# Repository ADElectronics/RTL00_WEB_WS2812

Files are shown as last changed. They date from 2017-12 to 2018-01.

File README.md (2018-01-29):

# Глупая гирлянда на RTL-00 и WS2812

Глупая гирлянда с WEB управлением на основе RTL-00 (RTL8710AF) и WS2812. :)<br>

Описание проекта - [RTL-00, WS2812 — Глупая гирлянда](https://adelectronics.ru/2017/12/29/rtl-00-ws2812-глупая-гирлянда/)<br>
Требуется SDK А для сборки - [RTL_SDK_A](https://github.com/ADElectronics/RTL_SDK_A)<br>

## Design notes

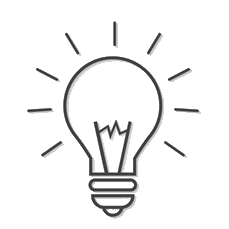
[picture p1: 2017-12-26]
Firmware/WEBFiles/on.gif

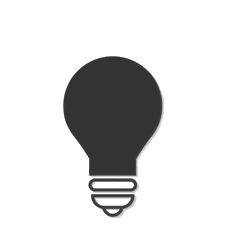
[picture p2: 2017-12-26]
Firmware/WEBFiles/off.gif

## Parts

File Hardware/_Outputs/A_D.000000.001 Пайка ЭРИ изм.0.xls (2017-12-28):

ПЕРЕЧЕНЬ КОМПЛЕКТУЮЩИХ
Глупая гирлянда
A_D.000000.001 Э3
Позиционный номер компонента | Тип компонента | Компонент | Производитель | Спецификация | Количество |  | Примечание
 |  |  |  |  | на ед. | на комплект
A1 | Модуль | RTL-00 | B&T |  | 1 | 1 | RTL-01, PADI-00, MJIOT-AMB-01S
C1, C2, C4, C5, C6 | Конденсатор | GRM188R71C104KA01D | Murata |  | 5 | 5
C3, C7 | Конденсатор | GRM21BR60J226ME39L | Murata |  | 2 | 2
DA1 | Микросхема | MIC5205-3.3YM5 | Micrel |  | 1 | 1 | MIC5205-3.3BM5
DD1 | Микросхема | SN74AVC1T45DBVR | Texas Instruments |  | 1 | 1 | SN74AVC1T45DBVT
HL1 | Индикатор единичный | BL-LS0603GC |  |  | 1 | 1
HL2 | Индикатор единичный | BL-LS0603HC |  |  | 1 | 1
R1, R2, R3, R4 | Резистор | RC0603JR-0710KL | Yageo |  | 4 | 4 | CR0603-JW-103E
R5, R6 | Резистор | RC0603JR-07330RL | Yageo |  | 2 | 2 | CR0603-JW-331E
R7 | Резистор | RC0603JR-074K7L | Yageo |  | 1 | 1
R8 | Резистор | RC0603JR-07100R | Yageo |  | 1 | 1 | CR0603-JW-101E
SB1 | Переключатель | SKQGABE010 | ALPS |  | 1 | 1
VD1 | Диод | SD103CW |  |  | 1 | 1
XP1 | Вилка | PLS-3 |  |  | 1 | 1
XP2 | Вилка | PLS-5 |  |  | 1 | 1
 |  |  |  |  | Комплект плат, ед.:
 |  |  |  |  |  | 1

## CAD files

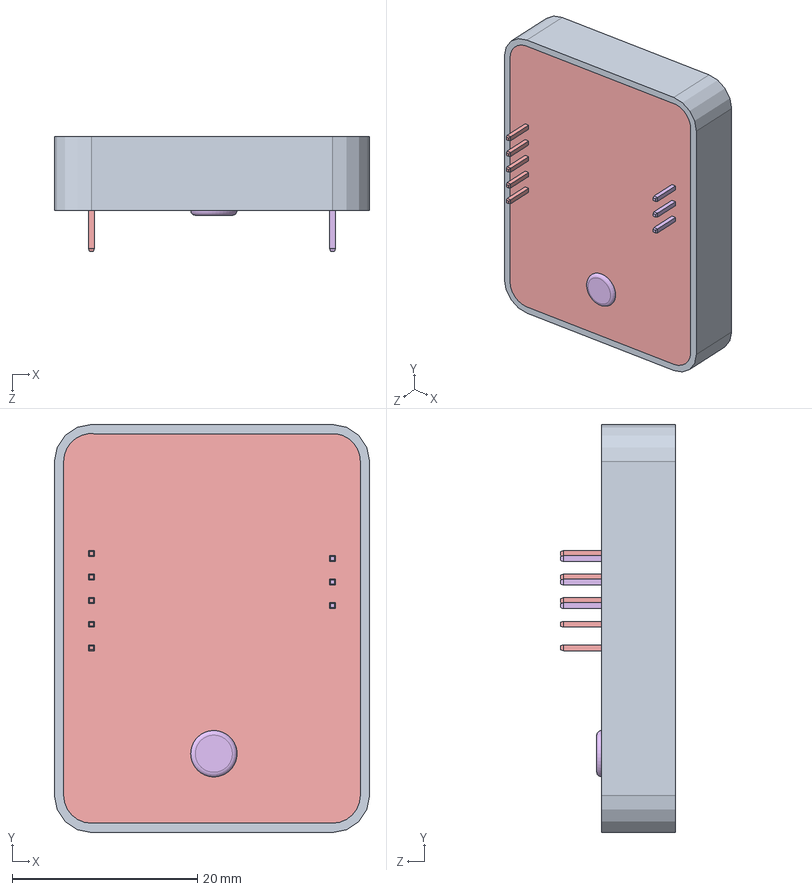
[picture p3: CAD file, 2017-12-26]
Device body/Сборка.SLDASM
34.0 x 44.0 x 12.4 mm
Base
Board
User_Library-Chip_Resistor2 x 5
User_Library-CAPC1608X09 x 5
User_Library-SOD123-1
Extruded
circuitworks-sot-23-5
User_Library-SOT23-6-2
User_Library-CAPC2013X10 x 2
User_Library-button1
Top
Button

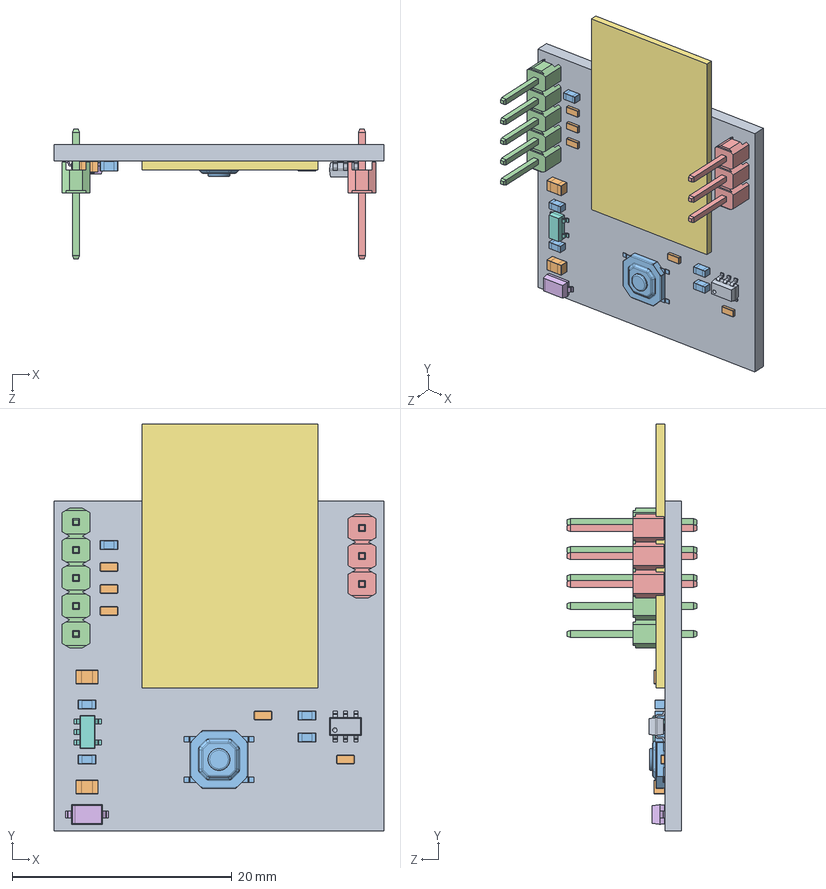
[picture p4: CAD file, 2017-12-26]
Device body/PCB/A_D.000000.001.SLDASM
30.0 x 37.0 x 11.8 mm
Board
User_Library-Chip_Resistor2 x 5
User_Library-CAPC1608X09 x 5
User_Library-SOD123-1
Extruded
circuitworks-sot-23-5
User_Library-SOT23-6-2
User_Library-CAPC2013X10 x 2
User_Library-button1

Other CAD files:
Device body/PCB/A1.sldasm
Device body/PCB/C3.sldasm
Device body/PCB/R1.sldasm
Device body/PCB/C6.sldasm
Device body/PCB/R4.sldasm
Device body/PCB/DD1.sldasm
Device body/PCB/C4.sldasm
Device body/PCB/R2.sldasm
Device body/PCB/C2.sldasm
Device body/PCB/C5.sldasm
Device body/PCB/VD1.sldasm
Device body/PCB/DA1.sldasm
Device body/PCB/C7.sldasm
Device body/PCB/XP1.sldasm
Device body/PCB/SB1.sldasm
Device body/PCB/R5.sldasm
Device body/Base.SLDPRT
Device body/Base.STL
Device body/Button.SLDPRT
Device body/Button.STL
Device body/PCB/324089616.sldasm
Device body/PCB/Board.sldprt
Device body/PCB/C1.sldasm
Device body/PCB/Extruded.sldprt
Device body/PCB/PLS-3.sldprt
Device body/PCB/PLS-5.sldprt
Device body/PCB/R3.sldasm
Device body/PCB/User_Library-CAPC1608X09.sldprt
Device body/PCB/User_Library-CAPC2013X10.sldprt
Device body/PCB/User_Library-Chip_Resistor2.sldprt
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

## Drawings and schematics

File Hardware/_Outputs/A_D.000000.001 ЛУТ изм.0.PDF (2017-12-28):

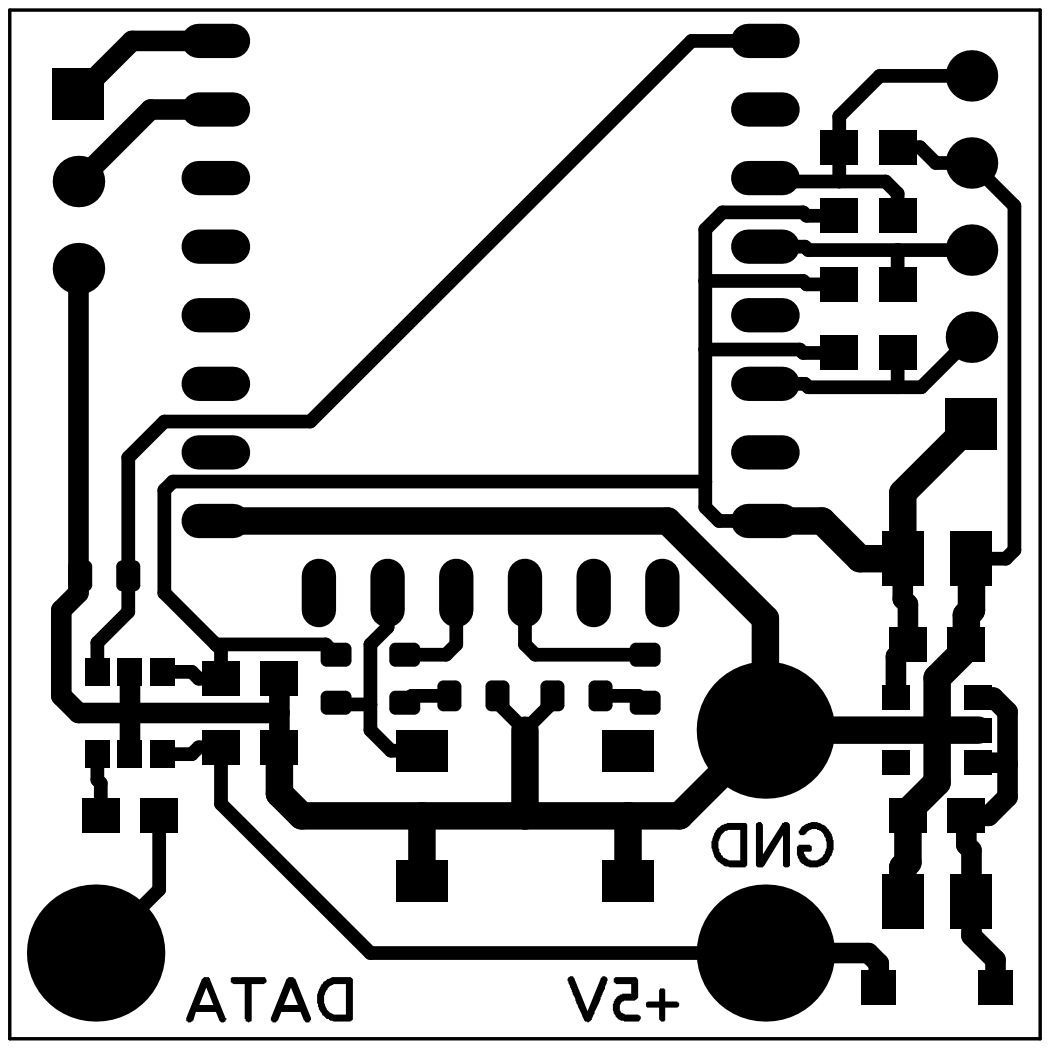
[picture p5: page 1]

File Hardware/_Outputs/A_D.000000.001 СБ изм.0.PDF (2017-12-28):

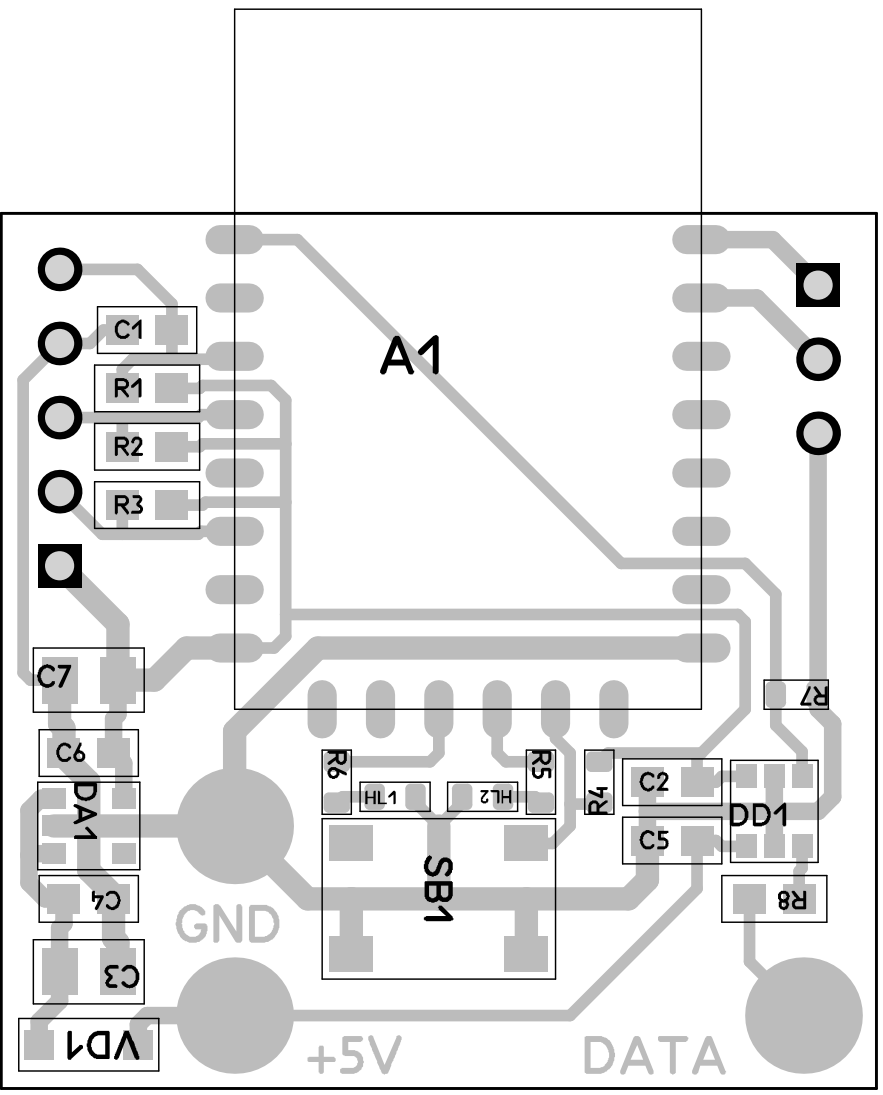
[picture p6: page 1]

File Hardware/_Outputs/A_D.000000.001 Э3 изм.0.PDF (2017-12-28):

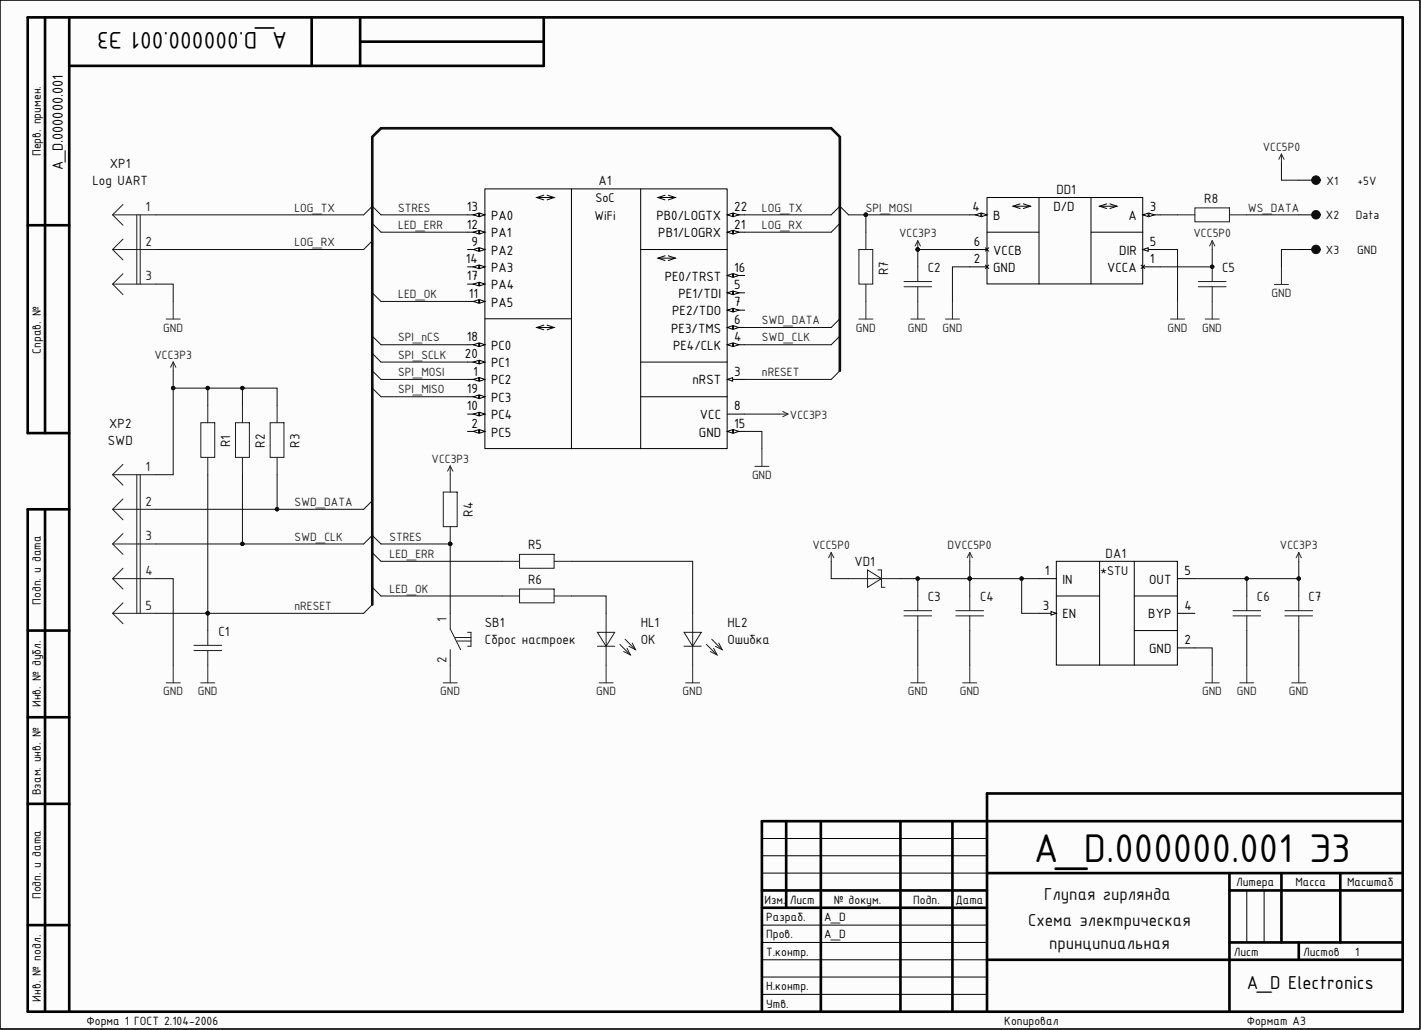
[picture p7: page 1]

PA1 12 PA0 13 | SoC WiFi

PA2 9 | | SWD_DATA

Инв. № подл. Подп. и дата Взам. инв. № Инв. № дубл. Подп. и дата

Глупая гирлянда Схема электрическая принципиальная | Литера | Масса | Масштаб

Изм. | Лист | № докум. | Подп. | Дата
Разраб. | | A_D
Пров. | | A_D
Т.контр. | | | | | Лист | Листов 1

Н.контр.
Утв.

A_D Electronics

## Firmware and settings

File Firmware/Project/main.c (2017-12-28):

#include "platform_autoconf.h"
#include "autoconf.h"
#include "FreeRTOS.h"
#include "task.h"
#include "diag.h"
#include "hal_crypto.h"
#include "hal_log_uart.h"
#include "hal_misc.h"
#include "diag.h"
#include "tcm_heap.h"
#include "hal_platform.h"
#include "rtl8195a_sys_on.h"
#include "hal_timer.h"

#ifdef CONFIG_WDG_ON_IDLE
#include "rtl8195a_wdt.h"
#include "hal_peri_on.h"
#include "rtl8195a_peri_on.h"
#endif

// Customized Signature (Image Name)
#include "section_config.h"
#ifndef _MSC_VER // IntelliSense
SECTION(".custom.validate.rodata")
#endif
const unsigned char cus_sig[32] = "WEB Sample";

#ifdef CONFIG_DEBUG_LOG
#define DEBUG_MAIN_LEVEL CONFIG_DEBUG_LOG
#else
#define DEBUG_MAIN_LEVEL 0
#endif

#ifndef CONFIG_INIT_NET
#define CONFIG_INIT_NET             1
#endif
#ifndef CONFIG_INTERACTIVE_MODE
#define CONFIG_INTERACTIVE_MODE     1
#endif

extern void WDGStart(void);
extern void user_init_thrd(void);
extern void user_ws_thrd(void);

void ShowMemInfo(void)
{
	DiagPrintf("\nCLK CPU\t\t%d Hz\nRAM heap\t%d bytes\nTCM heap\t%d bytes\n", HalGetCpuClk(), xPortGetFreeHeapSize(), tcm_heap_freeSpace());
}

int main(void)
{
#if DEBUG_MAIN_LEVEL > 3
	 ConfigDebugErr  = -1;
	 ConfigDebugInfo = ~(_DBG_SPI_FLASH_);//|_DBG_TCM_HEAP_);
	 ConfigDebugWarn = -1;
	 CfgSysDebugErr = -1;
	 CfgSysDebugInfo = -1;
	 CfgSysDebugWarn = -1;
#endif

#ifdef CONFIG_WDG_ON_IDLE
	HAL_PERI_ON_WRITE32(REG_SOC_FUNC_EN, HAL_PERI_ON_READ32(REG_SOC_FUNC_EN) & 0x1FFFFF);
#if CONFIG_DEBUG_LOG > 3
	WDGInitial(CONFIG_WDG_ON_IDLE * 3000); // 30 s
#else
	WDGInitial(CONFIG_WDG_ON_IDLE * 1000); // 4 s
#endif
	WDGStart();
#endif

#if (defined(CONFIG_CRYPTO_MODULE) && (CONFIG_CRYPTO_STARTUP))
	 if(rtl_cryptoEngine_init() != 0 ) 
	 {
		 DBG_8195A("Crypto engine init failed!\n");
	 }
#endif

#if DEBUG_MAIN_LEVEL > 1
	vPortFree(pvPortMalloc(4)); // Init RAM heap
	ShowMemInfo(); // RAM/TCM/Heaps info
#endif

	// wlan & user_start intialization
	xTaskCreate(user_init_thrd, "user_init", 512, NULL, tskIDLE_PRIORITY + 2 + PRIORITIE_OFFSET, NULL);
	xTaskCreate(user_ws_thrd, "user_ws", 512, NULL, tskIDLE_PRIORITY + 1 + PRIORITIE_OFFSET, NULL);

	// Enable Schedule, Start Kernel
#if defined(CONFIG_KERNEL) && !TASK_SCHEDULER_DISABLED
#ifdef PLATFORM_FREERTOS
	vTaskStartScheduler();
#endif
#else
	RtlConsolTaskRom(NULL);
#endif
}

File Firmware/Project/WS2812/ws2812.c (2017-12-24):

#include "ws2812.h"

/* Quick and dirty, we use one big DMA buffer for the whole strip length.
 * TODO: use smaller DMA buffer and fill in bit patterns on the fly */
uint8_t dma_buffer[WS2812_DMABUF_LEN(WS2812_LEDS_MAX)];

/* scale uint8 value from range 2-255 to range 0-scale */
static inline uint8_t WS2812_Scale(uint8_t value, uint8_t scale)
{
	uint32_t tmp;

	tmp = value * scale;
	tmp /= 256;

	return (uint8_t)tmp;
}

// wake up waiting tasks when DMA transfer is complete 
static void master_tr_done_callback(void *pdata, SpiIrq event)
{
	BaseType_t task_woken, result;
	ws2812_t *cfg;

	task_woken = pdFALSE;
	cfg = (ws2812_t *) pdata;

	switch (event) 
	{
		case SpiRxIrq:
			break;
			
		case SpiTxIrq:
			result = xEventGroupSetBitsFromISR(cfg->events, BIT_DONE, &task_woken);
			if(result == pdPASS)
			{
				portYIELD_FROM_ISR(task_woken);
			}
			break;
			
		default:
			DBG_8195A("WS2812: Unknown SPI irq event!\n");
	}
}

static void WS2812_HSV2RGB(ws2812_hsv_t *hsv, ws2812_rgb_t *rgb)
{
	//uint8_t r, g, b;
	uint8_t hue, sat, val;
	uint8_t base, sector, offset;
	uint8_t rise, fall;

	// scale hue to range 0- 3*64. Makes subsequent calculations easier
	hue = WS2812_Scale(hsv->hue, 192);
	sat = hsv->sat;
	val = hsv->value;

	sector = hue / 64;
	offset = hue % 64;

	// get common white base level and remaining colour amplitude
	base = 255 - sat;

	rise = (offset * sat * 4) / 256;
	fall = 255 - base - rise;

	rise = (rise * val) / 256;
	fall = (fall * val) / 256;
	base = (base * val) / 256;

	rgb->r = base;
	rgb->g = base;
	rgb->b = base;

	switch (sector)
	{
	case 0:
		rgb->r += fall;
		rgb->g += rise;
		break;
	case 1:
		rgb->g += fall;
		rgb->b += rise;
		break;
	case 2:
		rgb->r += rise;
		rgb->b += fall;
		break;
	}
}

// convert a RGB byte into SPI data stream with 2 bits per byte
static uint8_t *WS2812_RGB2PWM(uint8_t *dst, const uint8_t colour)
{
	uint8_t cnt, data = colour;

	for (cnt = 0; cnt < 4; cnt++)
	{
		switch (data & 0xC0)
		{
		case 0x00:
			*dst = WS2812_BITS_00;
			break;
		case 0x40:
			*dst = WS2812_BITS_01;
			break;
		case 0x80:
			*dst = WS2812_BITS_10;
			break;
		case 0xC0:
			*dst = WS2812_BITS_11;
			break;
		}
		dst++;
		data <<= 2;
	}
	return dst;
}

int32_t WS2812_Tx(ws2812_t *cfg, uint16_t delay)
{
    EventBits_t rcvd_events;
    TickType_t timeout;
    BaseType_t status;

    // wait for any SPI transfer to finish
    while(cfg->spi_master.state & SPI_STATE_TX_BUSY)
	{
        vTaskDelay(0);
    }

    // obey requested delay
    if(delay > 0)
	{
        vTaskDelay(delay);
    }

    // lock the DMA buffer mutex while it is transferred
    status = xSemaphoreTake(cfg->mutex, configTICK_RATE_HZ);
    if(status != pdTRUE)
	{
        printf("WS2812: [%s] Timeout waiting for config mutex.\n", __func__);
		xSemaphoreGive(cfg->mutex);
		return -1;
    }
    
    if(cfg->dma_buff == NULL || cfg->buff_len == 0)
	{
        printf("WS2812: [%s] DMA buffer invalid\n", __func__);
		xSemaphoreGive(cfg->mutex);
		return -1;
    }

    xEventGroupClearBits(cfg->events, BIT_DONE);
    spi_master_write_stream_dma(&cfg->spi_master, (char *)(cfg->dma_buff), cfg->buff_len);

    timeout = 1000 / portTICK_PERIOD_MS;
    rcvd_events = xEventGroupWaitBits(
                        cfg->events, 
                        BIT_DONE,        // wait for DMA TX done
                        pdTRUE,          // clear event bit
                        pdFALSE,         // do not wait for all bits to be set
                        timeout );

    if(!(rcvd_events & BIT_DONE))
	{
        printf("WS2812: [%s] DMA timeout\n", __func__);
		xSemaphoreGive(cfg->mutex);
		return -1;
    }

    xSemaphoreGive(cfg->mutex);
    return 1;
}

int32_t ws2812_Update(ws2812_t *cfg, ws2812_hsv_t hsv_values[], uint32_t strip_len, uint16_t delay)
{
    uint32_t i;
    uint8_t *bufp;
    uint16_t len;
    BaseType_t status;
	ws2812_rgb_t rgb;

    // Ждем, пока освободится буффер DMA
    while(cfg->spi_master.state & SPI_STATE_TX_BUSY)
	{
        vTaskDelay(0);
    }

    status = xSemaphoreTake(cfg->mutex, configTICK_RATE_HZ);
    if(status != pdTRUE)
	{
        printf("WS2812: [%s] Timeout waiting for config mutex.\n", __func__);
		return -1;
    }
    bufp = &(cfg->dma_buff[0]);
    
    // Проверка на вмещаемость и копирование
    len = min(strip_len, cfg->strip_len);
    for(i = 0; i < len; i++)
	{
        WS2812_HSV2RGB(&hsv_values[i], &rgb);
        bufp = WS2812_RGB2PWM(bufp, rgb.g);
        bufp = WS2812_RGB2PWM(bufp, rgb.r);
        bufp = WS2812_RGB2PWM(bufp, rgb.b);
    }
    
    // Все не используемые пиксели - выключаем
    if(cfg->strip_len > len)
	{
        memset(bufp, WS2812_BITS_00, cfg->strip_len - len);
        bufp += cfg->strip_len - len;
    }

    memset(bufp, 0x0, WS2812_RESET_LEN); 
    xSemaphoreGive(cfg->mutex);

	return WS2812_Tx(cfg, delay);
}

ws2812_t *ws2812_Init(uint16_t strip_len)
{
    int32_t result;
    ws2812_t *cfg;

    result = 0;

    cfg = malloc(sizeof(ws2812_t));
    if(cfg == NULL)
	{
        printf("WS2812: [%s] malloc for cfg failed\n", __func__);
        result = -1;
        goto err_out;
    }

    memset(cfg, 0x0, sizeof(ws2812_t));

    cfg->mutex = xSemaphoreCreateMutex();
    if(cfg->mutex == NULL)
	{
        printf("WS2812: [%s] Mutex creation failed\n", __func__);
        result = -1;
        goto err_out;
    }
    
    cfg->events = xEventGroupCreate();
    if(cfg->events == NULL)
	{
        printf("WS2812: [%s] Creating event group failed\n", __func__);
        result = -1;
        goto err_out;
    }

    spi_init(&(cfg->spi_master), WS2812_SPI_MOSI, WS2812_SPI_MISO, WS2812_SPI_SCLK, WS2812_SPI_CS);
    spi_format(&(cfg->spi_master), 8, 3, 0);
    spi_frequency(&(cfg->spi_master), WS2812_SPI_FREQ);
    spi_irq_hook(&(cfg->spi_master), (spi_irq_handler)master_tr_done_callback, (uint32_t)cfg);

    result = ws2812_SetLen(cfg, strip_len);
    if(!result)
	{
        printf("WS2812: [%s] ws2812_set_len() failed\n", __func__);
    }

err_out:
    if(!result && cfg != NULL)
	{
        if(cfg->mutex != NULL)
		{
            vQueueDelete(cfg->mutex);
        }

        if(cfg->events != NULL)
		{
            vEventGroupDelete(cfg->events);
        }

        if(cfg->dma_buff != NULL)
		{
            free(cfg->dma_buff);
        }

        free(cfg);
        cfg = NULL;
    }
    
    return cfg;
}
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

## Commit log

2017-12-28 first release
    [A_D.000000.001 Пайка ЭРИ изм.0.xls, A_D.000000.001.PcbDoc, A_D.000000.001.SchDoc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]
2018-01-05 Fix main lamp on\off switch
    Main lamp switch not worked on Opera\Chrome, but worked on Edge - now worked normal on all browsers.
2018-01-29 SDK update
    [ameba1.cfg]
2018-01-29 flasher fix
    [ameba1.cfg]
